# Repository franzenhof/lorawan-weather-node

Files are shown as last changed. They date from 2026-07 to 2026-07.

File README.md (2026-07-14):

# LoRaWAN Weather Node

Firmware for a custom-designed PCB based on a **Heltec WiFi LoRa 32 V3** (ESP32-S3).  
The node measures wind speed, wind direction, rainfall, temperature, humidity, and barometric pressure and transmits the data via **LoRaWAN (OTAA, region configurable; default: EU868)** to a private ChirpStack server.

The images below give a quick impression of the hardware journey from empty PCB to finished node and show how the measured data can be visualized in Grafana.

## Project in Pictures

<table>
  <tr>
    <td align="center" width="33%">
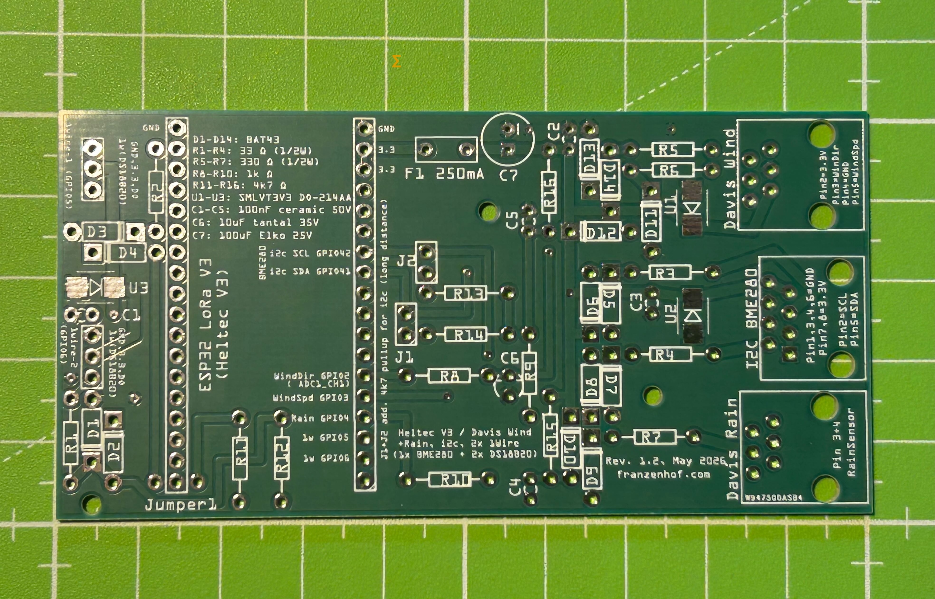
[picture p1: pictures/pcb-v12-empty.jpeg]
PCB Rev 1.2, empty board
      
      <br><strong>PCB, empty</strong>
    </td>
    <td align="center" width="33%">
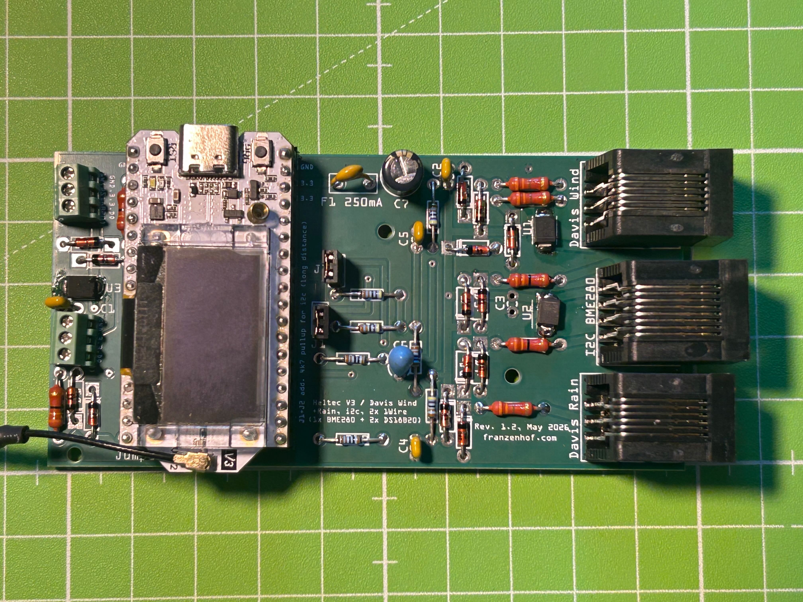
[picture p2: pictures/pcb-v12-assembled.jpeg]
PCB Rev 1.2, assembled board
      
      <br><strong>PCB, assembled</strong>
    </td>
    <td align="center" width="33%">
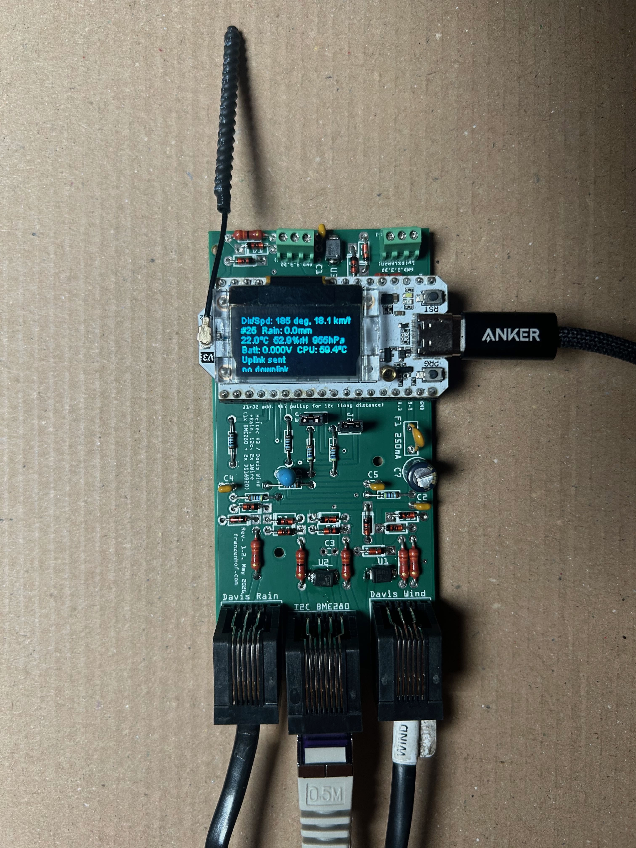
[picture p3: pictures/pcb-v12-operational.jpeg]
PCB Rev 1.2, operational board
      
      <br><strong>PCB, in operation</strong>
    </td>
  </tr>
</table>

<table>
  <tr>
    <td align="center" width="50%">
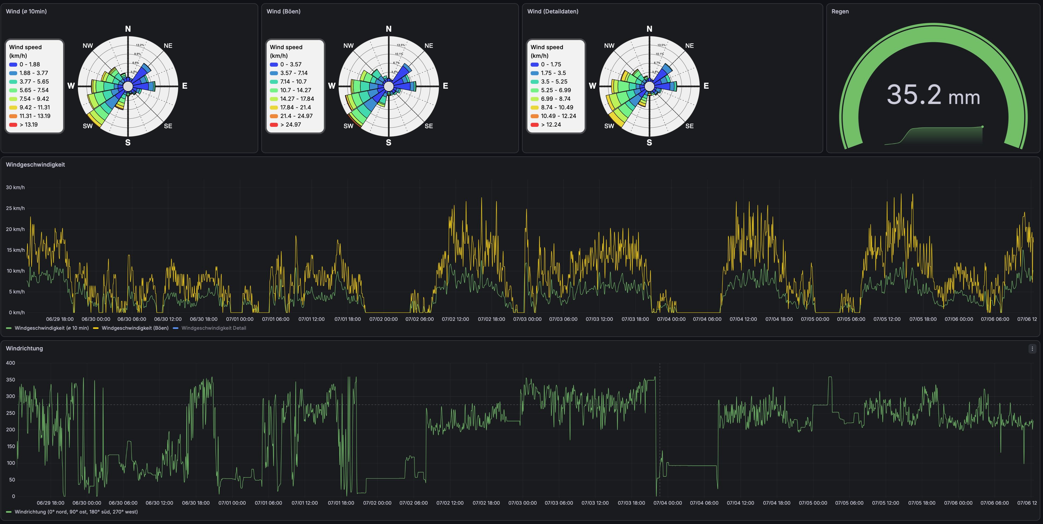
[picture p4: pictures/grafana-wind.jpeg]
Grafana dashboard for wind data
      
      <br><strong>Grafana: wind data</strong>
    </td>
    <td align="center" width="50%">
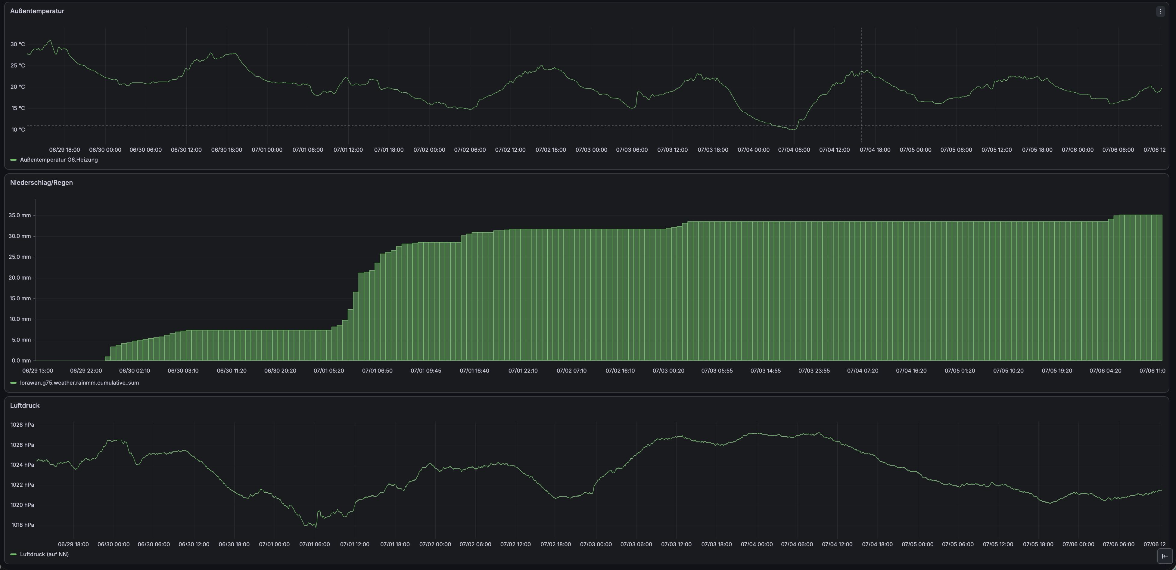
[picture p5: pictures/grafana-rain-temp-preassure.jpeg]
Grafana dashboard for rain, temperature and pressure
      
      <br><strong>Grafana: rain, temperature and pressure</strong>
    </td>
  </tr>
</table>

The following screenshots show the Wi-Fi configuration flow. This setup is designed to be quick and beginner-friendly, even without USB tools.

<table>
  <tr>
    <td align="center" width="50%">
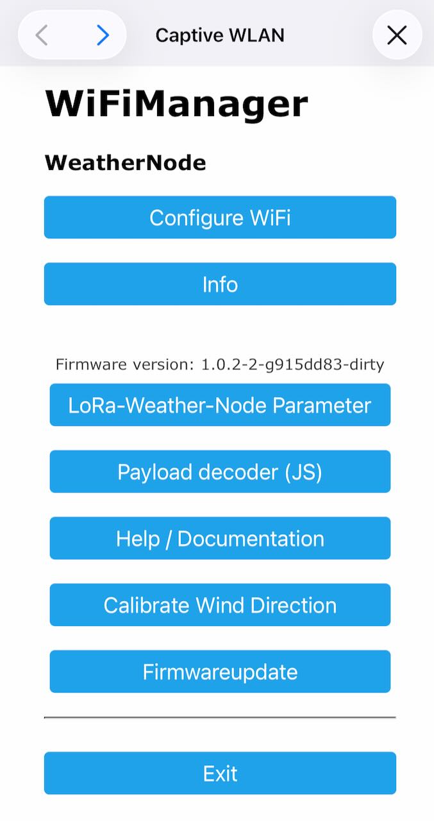
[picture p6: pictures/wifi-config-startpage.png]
Wi-Fi manager start page
      
      <br><strong>Wi-Fi manager: start page</strong>
    </td>
    <td align="center" width="50%">
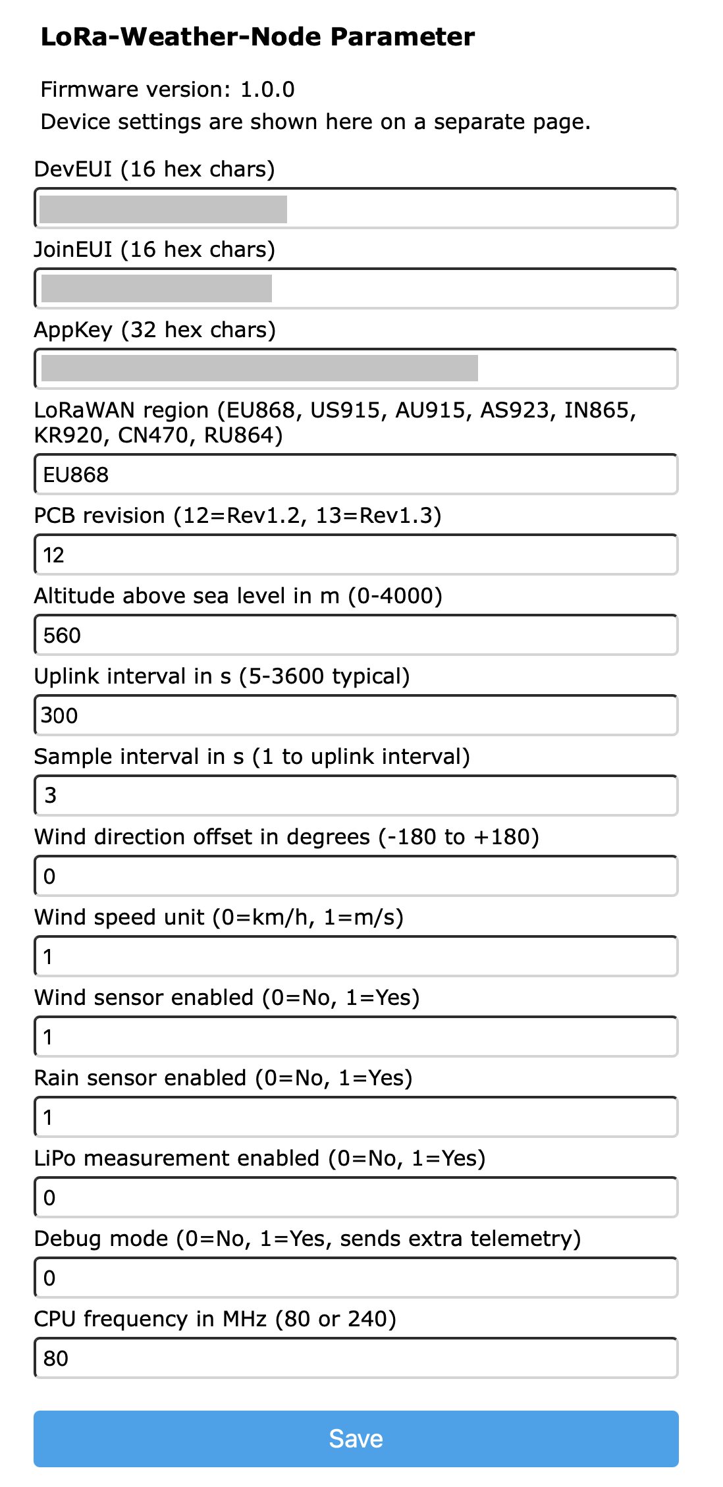
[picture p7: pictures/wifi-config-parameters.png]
Wi-Fi manager parameters page
      
      <br><strong>Wi-Fi manager: parameter page</strong>
    </td>
  </tr>
</table>

<table>
  <tr>
    <td align="center" width="50%">
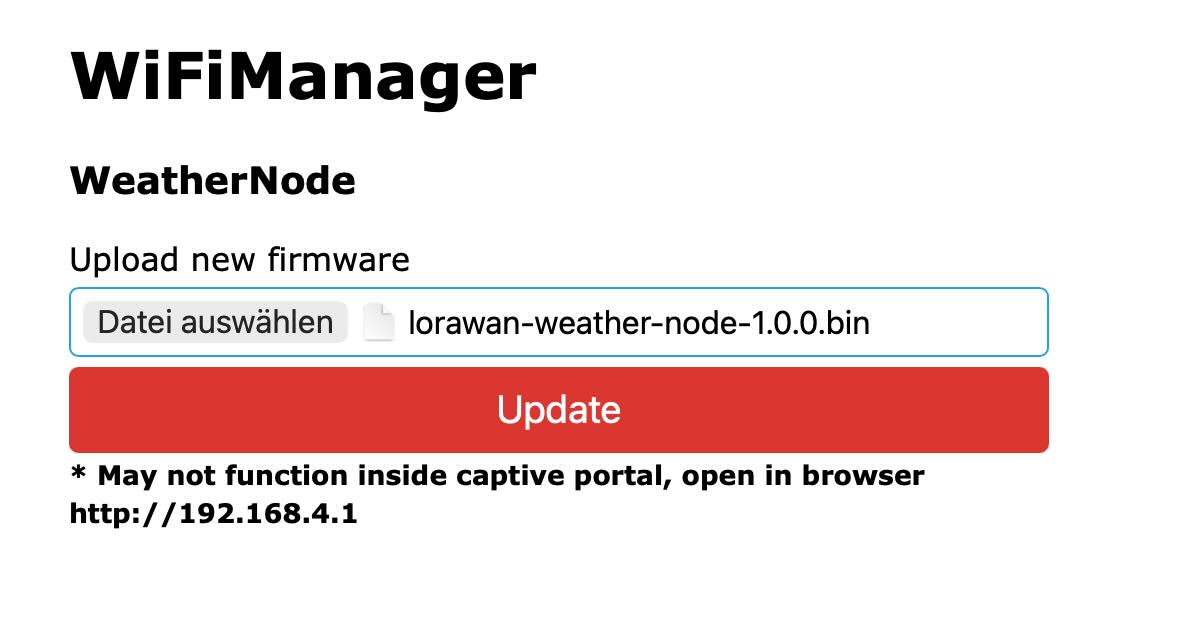
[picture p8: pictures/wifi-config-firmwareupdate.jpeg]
Wi-Fi manager firmware update page
      
      <br><strong>Wi-Fi manager: firmware update</strong>
    </td>
    <td align="center" width="50%">
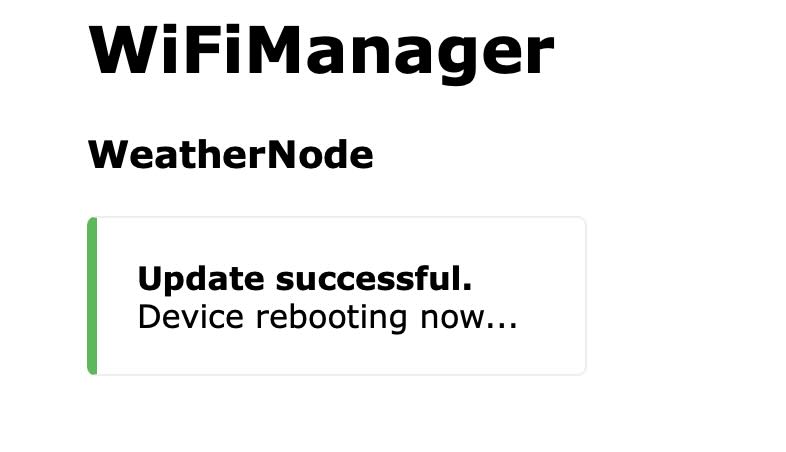
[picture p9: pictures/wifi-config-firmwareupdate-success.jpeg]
Wi-Fi manager firmware update successful
      
      <br><strong>Wi-Fi manager: update successful</strong>
    </td>
  </tr>
</table>

---

## 📄 License & Open Source

This project is fully open-source. To support both software developers and hardware makers, it is dual-licensed:

* **Software / Firmware:** Licensed under the **[MIT License](LICENSE-SOFTWARE)**. You can freely use, modify, and distribute the code.
* **Hardware (Schematics, PCB & 3D Files):** Licensed under the **[CERN-OHL-P v2](LICENSE-HARDWARE)** (CERN Open Hardware Licence – Permissive). You are free to manufacture, modify, and distribute the hardware designs.

*Developed with 🚜 and 💻 by Gerhard Massenbichler at Franzenhof.*

## Use Case

```
[USB-C power supply] ──► [Heltec WiFi LoRa V3]
                              │        │
                   [Davis 6410]    [BME280 via RJ45]
                   Wind sensor           │
                   │                [DS18B20 × 3]
                   [Davis AeroCone]  [LiPo optional]
                   Rain sensor
                              │
                              [LoRaWAN (default EU868)]
                              │
                       [ChirpStack server]
```

The node runs continuously (no deep sleep), measures without interruption, and transmits a LoRaWAN uplink every configurable number of seconds. Typical uplink interval: 60–300 seconds.

---

## Hardware

| Component | Function |
|---|---|
| Heltec WiFi LoRa 32 V3 | Microcontroller (ESP32-S3), LoRa SX1262, OLED display 128×64 |
| Davis 6410 Anemometer | Wind speed (reed switch) + wind direction (potentiometer 20 kΩ) |
| Davis AeroCone / Standard (typically 6466M) | Rainfall (reed switch, 0.2 mm/pulse) |
| BME280 | Temperature / humidity / barometric pressure (I²C 0x76, up to 2 m RJ45 cable) |
| DS18B20 | Up to 3 temperature sensors (1-Wire, external) |
| LiPo battery | Optional; voltage measurement via voltage divider + ADC |
| Custom PCB Rev 1.2 / 1.3 | ESD protection, pull-ups, RC filter, polyfuse |

### Custom PCB

In addition to mechanically connecting the connectors, the PCB provides the following protection functions for all external interfaces:

- **TVS diodes** (SMLVT3V3) directly at each external connector as primary ESD coarse protection  
- **BAT43 Schottky clamp diodes** as secondary protection clamps before the GPIO pins  
- **Series resistors** (330 Ω / 1 kΩ) for current limiting  
- **RC low-pass filter** (4.7 kΩ + 100 nF, τ ≈ 0.47 ms) for hardware debouncing of the reed switches  
- **Polyfuse F1** (250 mA) for short-circuit protection of the 3.3 V sensor supply  
- **Additional I²C pull-ups** (4.7 kΩ, jumper J1/J2) for longer BME280 cable runs up to 2 m

---

## GPIO Pinout

### Fixed Pins (revision-independent)

| GPIO | Function | Direction | Note |
|---|---|---|---|
| **0** | User button | IN (pull-up) | Short press: display 20 s; long press (≥ 3 s): Wi-Fi portal |
| **1** | LiPo ADC | IN (ADC1_CH0) | Voltage divider R13/R14 (390 Ω / 100 Ω) |
| **37** | BAT_CTRL | OUT | HIGH enables ADC measurement path (Heltec V3 internal from board rev. 3.2) |
| **41** | I²C SDA (BME280) | IN/OUT | Wire2, 50 kHz, address 0x76 |
| **42** | I²C SCL (BME280) | OUT | Wire2 |

### Revision-Dependent Pins

| GPIO Rev 1.2 | GPIO Rev 1.3 | Function |
|:---:|:---:|---|
| **2** | **4** | Wind direction ADC (ADC1_CH1) – Davis potentiometer 0–3.3 V → 0–359°, C6 = 10 µF low-pass |
| **3** | **2** | Wind speed (PCNT Unit 0, reed switch) |
| **4** | **5** | Rain (PCNT Unit 1, reed switch) |
| **5** | **6** | 1-Wire bus (DS18B20, up to 3 sensors) |
| **6** | **3** | unused / free |
| – | **47** | 1-Wire high-side switch (OUT, HIGH = bus powered) |

> The active PCB revision is configured in the Wi-Fi portal (default: **13** for Rev 1.3).

### Wind Sensor (Davis 6410) – RJ11 6-pin

| Pin | Color | Function |
|-----|---|---|
| 1 | – | n/c |
| 2 | Yellow | VCC 3.3 V (potentiometer supply) |
| 3 | Green | Wind direction (potentiometer wiper → ADC) |
| 4 | Red | GND |
| 5 | Black | Wind speed (reed switch → PCNT) |
| 6 | – | n/c |

### Rain Sensor (Davis 6466M) – RJ11 6-pin

| Pin | Color | Function |
|-----|---|---|
| 3 | Green/Yellow | Reed switch → PCNT |
| 4 | Red | GND |
| others | – | n/c |

> Wire colors 3 and 4 may be swapped depending on the cable batch – both variants work since the reed switch is polarity-independent.

### BME280 – RJ45 (solder module-side onto breakout board)

| Pins | Function |
|---|---|
| 1, 2, 4, 6 | GND |
| 7, 8 | VCC 3.3 V |
| 3 | SCL |
| 5 | SDA |

> Jumpers J1 and J2 on the PCB activate the additional 4.7 kΩ I²C pull-ups for cable lengths over 0.5 m.

---

## Measurement Principles

### Wind Speed
The Davis 6410 anemometer contains a **reed switch** that closes once per revolution.  
The ESP32 hardware pulse counter (**PCNT**) counts edges without CPU load.  
Conversion per Davis specification:

```
1 revolution/s = 2.25 mph = 3.62 km/h
Wind speed [km/h] = pulses/s × 2.25 × 1.60934
```

The **maximum wind gust** (maximum per uplink interval) is also captured and transmitted separately.

### Wind Direction
The Davis 6410 contains a **potentiometer (20 kΩ)** powered directly from VCC3.3.  
The wiper delivers a linear voltage from 0–3.3 V proportional to 0–359°.  
A configurable **north offset** (–180° to +180°) corrects the mounting orientation.

```
Raw value (0–4095, 12-bit ADC) → map(0, 4095, 0, 359) → + offset → mod 360
```

The low-pass filter C6 (10 µF + potentiometer source impedance ~10 kΩ) gives τ ≈ 100 ms (settling time ~500 ms), which is appropriate for typical vane movement speeds.

### Rainfall
The reed switch in the tipping bucket rain gauge fires one pulse per **0.2 mm of rainfall**.  
PCNT counts pulses in hardware. Rain rate is calculated as mm/h from the interval:

```
Rain [mm] = pulses × 0.2
Rain rate [mm/h] = rain [mm] / (interval [ms] / 3,600,000)
```

The since-start accumulator (`rainMMSinceStart`) survives normal operation in **RTC_DATA_ATTR** (lost on power interruption, resettable via downlink `0x01`).

### Temperatures (DS18B20)
Up to **3 sensors per bus** are detected automatically (`getDeviceCount()`).  
The index corresponds to the order of ROM addresses on the bus.

### Barometric Pressure (BME280)
The measured absolute pressure is converted to **sea level (QNH)** when a station altitude is configured:

```
QNH = absolute pressure × (1 - 0.0000226 × altitude[m])^(-5.255)
```

---

## CayenneLPP Payload Channels

| Channel | Type | Content | Unit | Active when |
|---|---|---|---|---|
| Ch 1 | Direction | Wind direction | ° | `windEn = 1` |
| Ch 1 | Analog Input | Avg wind speed | m/s or km/h | `windEn = 1` |
| Ch 2 | Analog Input | Wind gust (maximum) | m/s or km/h | `windEn = 1` |
| Ch 3 | Analog Input | Rain rate | mm/h | `rainEn = 1` |
| Ch 1 | Distance | Rain current cycle | mm | `rainEn = 1` |
| Ch 2 | Distance | Rain since start | mm | `rainEn = 1` |
| Ch 2 | Digital Input | Status bitfield (BME280, 1-Wire, send-fail count, wind unit) | bitfield | always |
| Ch 200 | Digital Input | Cycle counter (debug) | 0–255 | `debugMode = 1` |
| Ch 202 | Digital Input | Send fail counter (debug) | 0–255 | `debugMode = 1` |
| Ch 201 | Temperature | CPU temperature (debug) | °C | `debugMode = 1` |
| Ch 203 | Analog Input | Free heap (debug) | KiB | `debugMode = 1` |
| Ch 204 | Analog Input | Uptime (debug) | h | `debugMode = 1` |
| Ch 1 | Voltage | LiPo voltage | V | `lipoEn = 1` |
| Ch 1 | Rel. Humidity | Humidity | % | BME280 detected |
| Ch 1 | Baro. Pressure | Barometric pressure QNH | hPa | BME280 detected |
| Ch 2 | Baro. Pressure | Barometric pressure absolute | hPa | BME280 detected |
| Ch 1 | Temperature | BME280 temperature | °C | BME280 detected |
| Ch 2–4 | Temperature | DS18B20 sensor 0–2 | °C | sensor detected |

> **Rain encoding note:** The payload uses the CayenneLPP **Distance** type for rain values, but in this project it is interpreted as **mm** (`rain_cycle_mm`, `rain_since_start_mm`).
> Use the provided decoder in [chirpstack/decoder.js](chirpstack/decoder.js). Generic CayenneLPP decoders might assume meters, but you have to know the values are millimeters.

> In normal operation (`debugMode = 0`) no debug telemetry is sent.

> **Payload size:**  
> Minimal config (DS18B20 only): approx. 15–30 bytes – fits in DR0 (SF12, 51 bytes).  
> Full config (wind + rain + BME280 + 3× DS18B20 + LiPo): approx. 70–75 bytes – requires **DR2 (SF10)** or higher.  
> With a private ChirpStack server and normal gateway distance this is not an issue.

---

## Initial Configuration (Wi-Fi Portal)

### First boot
On first power-up (no DevEUI stored in NVS) the Wi-Fi portal opens **automatically**:

1. The OLED display shows **"Config Portal"**, the AP SSID, the URL and brief instructions
2. Connect your phone or laptop to the Wi-Fi network **"WeatherNode"** (no password)
3. Open **`http://192.168.4.1`** in a browser (most devices redirect automatically)
4. Enter all parameters and click *Save* → the device restarts automatically

### Re-opening the portal later
The portal can be opened at any time in two ways:

| Method | How |
|---|-----|
| **Button long press** | Hold the user button (GPIO 0) for **≥ 3 seconds** during normal operation |
| **LoRaWAN downlink** | Send byte `0x03` on FPort 1 (takes effect after the current send cycle) |

> **Note:** GPIO 0 must **not** be pressed during power-on or reset – this would activate the ESP32 bootloader instead of the firmware. The portal is therefore triggered by a long press *during operation* only.

### Firmware update via Wi-Fi portal (OTA)
Firmware updates can be done wirelessly while the portal is open:

1. Open the Wi-Fi portal (either long press on user button for at least 3 seconds, or LoRaWAN downlink `0x03`)
2. Connect to the board Wi-Fi **WeatherNode**
3. Open **http://192.168.4.1** in a normal browser
4. On the portal start page, click **Firmwareupdate**
5. Upload the `.bin` file and wait until the board reboots

> If the captive portal page does not allow file upload, open **http://192.168.4.1/update** directly in the browser.

| Parameter | Description | Default |
|---|---|---|
| DevEUI | 16 hex chars, from ChirpStack | – |
| JoinEUI | 16 hex chars, from ChirpStack | – |
| AppKey | 32 hex chars, from ChirpStack | – |
| LoRaWAN region | `EU868`, `US915`, `AU915`, `AS923`, `IN865`, `KR920`, `CN470`, `RU864` | EU868 |
| PCB revision | 12 = Rev 1.2, 13 = Rev 1.3 | 13 |
| Altitude above sea level (m) | Station altitude for QNH calculation | 560 |
| Uplink interval (s) | Target interval per measurement cycle | 300 |
| Sample interval (s) | Sub-sample interval within a cycle; ≤ uplink interval | 3 |
| Wind speed unit (0=km/h, 1=m/s) | Unit used for transmitted wind speed and gust values | 1 |
| Wind direction offset (°) | North correction during installation (−180 to +180) | 0 |
| Wind sensor (1=Yes) | Davis wind sensor enabled | 1 |
| Rain sensor (1=Yes) | Davis rain sensor enabled | 1 |
| LiPo measurement (1=Yes) | Voltage measurement via voltage divider enabled | 0 |
| Debug mode (1=Yes) | Adds cycle counter, CPU temp and extra diagnostics in high LPP channels | 0 |
| CPU frequency (80/240 MHz) | 80 MHz saves power; below 80 MHz not allowed (PCNT-APB dependency) | 80 |

> All settings are stored persistently in the **NVS (Non-Volatile Storage)** of the ESP32-S3 and survive restarts and firmware updates.

> Region input in the portal is validated. Unsupported values fall back to **EU868**.

### Debug mode

`debugMode` was introduced to support bench testing (for example without connected weather sensors) and fast diagnostics without affecting normal airtime.

When enabled, the node adds extra telemetry to high LPP channels (200+):

1. Cycle counter
2. CPU temperature
3. Send-fail counter
4. Free heap (KiB)
5. Uptime (hours)

When disabled (default), these values are not part of the uplink payload.

---

## User Button (GPIO 0)

| Press duration | When | Action |
|---|---|---|
| — | First boot (no DevEUI stored) | Wi-Fi portal opens automatically |
| Short press (< 3 s, on release) | Normal operation | Turn on OLED display for 20 s |
| Long press (≥ 3 s) | Normal operation or setup loops (join retries etc.) | Open Wi-Fi config portal → save → restart |

Button presses are detected via a **hardware interrupt** (GPIO CHANGE), so a short press is never missed – even while the LoRa send/receive window is blocking the main task for several seconds.

The display is **off** during normal operation to protect the SSD1306 driver and save power. It turns off automatically after 20 seconds. During the startup sequence (radio init, LoRaWAN join retries) the display stays on permanently so that status and error messages remain visible.

---

## ChirpStack Payload Decoder

The file `chirpstack/decoder.js` contains the JavaScript decoder for ChirpStack v3 and v4.

> **Tip:** The decoder file can also be downloaded directly from the device via the Wi-Fi config portal (*Payload decoder (JS)* button on the start page). The downloaded file is always version-matched to the running firmware.

**Adding the decoder to ChirpStack:**
1. In the ChirpStack web interface: *Device Profiles → Codec → JavaScript codec functions*
2. Paste the contents of `chirpstack/decoder.js`
3. Save – all values will appear as named JSON fields in the uplink events

**Example output (JSON):**
```json
{
  "wind_direction_deg": 247,
  "wind_speed_avg": 12.30,
  "wind_gust": 18.50,
  "rain_rate_mmh": 0.00,
  "rain_cycle_mm": 0.0,
  "rain_since_start_mm": 14.2,
  "cycle_counter": 42,
  "status": {
    "bme280_present": true,
    "bus1_has_sensors": true,
    "send_fail_count": 0,
    "wind_speed_unit": "m/s"
  },
  "battery_v": 3.98,
  "bme280_humidity_pct": 67.5,
  "bme280_pressure_qnh_hpa": 1013.2,
  "bme280_pressure_abs_hpa": 952.1,
  "bme280_temperature_c": 21.3,
  "ds18b20_0_c": 18.6,
  "ds18b20_1_c": 19.1
}
```

**Rain accumulator evaluation:**  
`rain_since_start_mm` is a cumulative counter. The delta between two received packets gives the actual rainfall – even if packets were lost in between.

---

## TTN (The Things Stack) Instead of Private ChirpStack

The node can be used with TTN/TTS as well. No payload format change is required, because the uplink is still standard CayenneLPP and the same decoder logic can be used.

### What to configure

1. In the Wi-Fi portal, set **LoRaWAN region** to the matching regional plan of your TTN deployment (for Europe typically `EU868`).
2. In TTN, create an end device using **OTAA**, LoRaWAN 1.0.x profile, and copy **DevEUI / JoinEUI / AppKey** into the node portal.
3. Add the payload formatter (JavaScript) in TTN by reusing [chirpstack/decoder.js](chirpstack/decoder.js) logic (field names can stay the same).

### Fair-use and practical intervals (EU868)

TTN strongly favors low airtime and low uplink rates. Practical guidance for weather telemetry:

1. Prefer **60 s to 300 s** uplink intervals.
2. Avoid high-spreading-factor operation with very short intervals.
3. Keep payload compact (disable unused sensors in the portal).

For TTN community networks, very short uplink intervals are generally not appropriate and may violate fair-use expectations depending on data rate and gateway conditions.

For TTN operation, keep `debugMode` disabled except for short troubleshooting windows.

### Do you need further firmware changes for TTN?

In most cases: **no functional code changes** are required. The key points are correct region and OTAA credentials.

---

## LoRaWAN Downlink Commands

Downlinks are sent on **FPort 1** with a single byte:

| Byte | Function |
|---|---|
| `0x01` | Reset rain accumulator (rain since start) to 0 |
| `0x02` | Restart device (triggers a new OTAA join) |
| `0x03` | Open Wi-Fi config portal (takes effect after the current send cycle completes) |
| `0x04` | Enable debug mode (persistent) |
| `0x05` | Disable debug mode (persistent) |

Parameter updates are sent on **FPort 1** with command `0x10`:

`[0x10, paramId, valueMSB, valueLSB, ...]`

Multiple parameter triplets may be included in one downlink. Values are interpreted as signed 16-bit and validated.

| Param ID | Parameter | Valid range / values |
|---|---|---|
| `1` | `uplinkIntervalSec` | `5..3600` |
| `2` | `sampleSec` | `1..uplinkIntervalSec` |
| `3` | `windEn` | `0` or `1` |
| `4` | `rainEn` | `0` or `1` |
| `5` | `lipoEn` | `0` or `1` |
| `6` | `debugMode` | `0` or `1` |
| `7` | `windDirOffsetDeg` | `-180..180` |
| `8` | `windUnitMs` | `0` or `1` |
| `9` | `cpuFreqMhz` | `80` or `240` |

Valid parameters are stored persistently in NVS immediately.

---

## Error Handling / Robustness

### Watchdog Timer
A **hardware watchdog** (120 s timeout) protects against hanging code.  
It is activated only **after a successful LoRaWAN join** – allowing slow joins and Wi-Fi portal operation to run without a WDT reset.

### Automatic Restart on Send Failures
After **10 consecutive send failures** an automatic restart is triggered to renew the LoRaWAN join (e.g. after gateway outage or session timeout).

### ADC Averaging
Wind ADC (direction) and battery ADC are averaged over **8 samples** to reduce ESP32-S3 ADC noise.

---

## Uplink Interval and Timing

The configured uplink interval is a **target value**: at the end of each cycle the code only waits the remaining time until the target interval (`millis()` delta). This prevents the measurement time (1-Wire conversion ~750 ms, LoRa airtime ~500 ms) from adding up twice.

```
Cycle start → measure → send → sleep(max(0, target − elapsed))
```

`Sample interval` and `Uplink interval` have different roles:

- **Sample interval** (`sampleSec`): defines how often sub-samples are taken within one uplink cycle.
- **Uplink interval** (`uplinkIntervalSec`): defines when one uplink is generated from the accumulated sub-samples.

Within one send cycle, values are combined as follows:

- **Wind speed (avg)**: arithmetic mean of all wind speed sub-samples.
- **Wind gust (max)**: maximum wind speed seen in all sub-samples of that cycle.
- **Wind direction**: vector average (sin/cos) across all sub-samples.
- **Rain cycle**: sum of rain pulses within the cycle.
- **Rain rate**: derived from the cycle rain amount and full cycle duration.
- **BME280 temperature/humidity/pressure**: arithmetic mean of all BME280 sub-samples.
- **DS18B20 temperatures**: measured once per uplink cycle (not sub-sampled/averaged over `sampleSec`).

**Minimum practical interval** in EU868 at DR5 (SF7): ~5 s (duty cycle restriction).  
For TTN/community networks, use significantly longer intervals (typically at least 60 s).  
**Default values:** uplink interval `300 s`, sample interval `3 s`.

---

## PCB Revisions

| Revision | Status | GPIO Wind Speed | GPIO Wind Dir | GPIO Rain | GPIO 1-Wire |
|---|---|:---:|:---:|:---:|:---:|
| **Rev 1.2** | In use | GPIO 3 | GPIO 2 | GPIO 4 | GPIO 5 |
| **Rev 1.3** | In preparation | GPIO 2 | GPIO 4 | GPIO 5 | GPIO 6 |

> Rev 1.3: The 5V input on the PCB (overvoltage protected) connects directly to the **5V pin of the Heltec WiFi LoRa V3** (Pin 2 on the J2 header of the controller board). GPIO 7 is completely free and unused.

> **Note on current firmware:** Both revisions now support only **one** 1-Wire bus (Rev 1.2: GPIO 5, Rev 1.3: GPIO 6). The former second bus is no longer addressed by the software.

**Changes in Rev 1.3 vs. 1.2:**
- TVS diode (SMLVT3V3 / U4) added at rain sensor connector
- GPIO numbers shifted by one (GPIO 3 was close to JTAG)
- 2nd 1-Wire bus removed; GPIO 6 freed → slot used for the 5V input

---

## Project Structure

```
├── src/
│   └── main.cpp             # Complete firmware
├── chirpstack/
│   └── decoder.js           # ChirpStack v3/v4 JavaScript payload decoder
├── pcblayout/
│   ├── pcb-layout with esd protection.fzz        # Fritzing Rev 1.3
│   ├── pcb-layout with esd protection_Schaltplan.png
│   ├── pcb-layout with esd protection_Leiterplatte.png
│   ├── pcb-layout with esd protection_bom.html
│   ├── pcb-layout with esd protection rev12.zip  # Gerber files Rev 1.2
│   ├── pcb-layout with esd protection rev13.zip  # Gerber files Rev 1.3
│   └── design_readme.txt    # Connector pin assignments
├── platformio.ini
└── README.md
```

---

## Libraries

| Library | Version | Purpose |
|---|---|---|
| RadioLib | ^7.6.0 | LoRaWAN stack (OTAA, EU868) |
| Heltec_ESP32_LoRa_v3 | ^0.9.2 | Board support (display, heltec_temperature) |
| LoRaWAN_ESP32 | ^1.2.0 | LoRaWAN session management (persistence) |
| CayenneLPP | ^1.6.1 | Payload encoding |
| WiFiManager | ^2.0.16-rc.2 | Wi-Fi configuration portal |
| Adafruit BME280 | ^2.2.4 | BME280 driver |
| Adafruit Unified Sensor | ^1.1.15 | Sensor abstraction |
| OneWire | ^2.3.8 | 1-Wire protocol |
| DallasTemperature | ^4.0.6 | DS18B20 driver |
| esp_task_wdt | (IDF built-in) | Hardware watchdog |

---

## Technical Notes

### PCNT and CPU Frequency
The hardware pulse counter (PCNT) uses the **APB clock** for its debounce filter.  
At CPU frequencies ≥ 80 MHz (PLL mode) the APB clock stays constant at 80 MHz.  
Below 80 MHz (XTAL mode) the APB clock drops proportionally → debounce filter timing becomes invalid.  
**Minimum allowed CPU frequency: 80 MHz.**

### 1-Wire with Runtime-Configured Pins
Because the GPIO numbers for 1-Wire are determined at runtime from the PCB revision, the `OneWire` and `DallasTemperature` objects are allocated on the heap with `new` (no static constructor with hard-coded pins possible).

### LoRaWAN Session Persistence
The `LoRaWAN_ESP32` library stores the LoRaWAN session (frame counters, DevAddr, session keys) in NVS. A restart does not necessarily trigger a new OTAA join.

### ADC Linearity
The ESP32-S3 ADC is non-linear (especially below 150 mV and above 3.1 V). For the wind direction potentiometer this is uncritical since values are mapped to 0–359° and the absolute measurement error remains < 5° in practice. For the battery voltage measurement a calibration factor is included in the code.

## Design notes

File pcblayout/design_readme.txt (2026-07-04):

All ESP32-Inputs connecting to Davis sensors are ESD protected (should protect against nearby lightning). 

i2c bus for bme280 sensor:
– Additional 4k7 pullups can be activated by jumper J1 and J2 for longer (max. 2 meter) distances. ESP32 pullups alone might be too weak. 

1wire bus:
- 4k7 Pullups
- Arduino default-Pinout: GND,VCC,DO

Original Rj11 jacks from the Davis-Sensors will fit to the terminals. 
Windsensor: 
- Pin 1: n/c
- Pin 2: 3.3 Volt (yellow wire)
- Pin 3: winddirection (potentiometer, green wire)
- Pin 4: ground/gnd (red wire)
- Pin 5: Windspeed (reedswitch, black wire)
- Pin 6: n/c

Rainsensor (wirecolor 3 and 4 might be swapped, this is no problem): 
- Pin 1: n/c
- Pin 2: n/c
- Pin 3: Windspeed (reedswitch, green/yellow wire)
- Pin 4: ground/gnd (red wire)
- Pin 5: n/c
- Pin 6: n/c

BME280 Sensor (use a rj45 jack and solder the bme280 onto it). CAT6-Cable with up to 2 (perhaps 3) meter length should work. Activate pullups on the board (J1 and J2)
- Pin 1,2,4,6 = Ground/gnd
- Pin 7,8 = VCC 3.3 Volt 
- Pin 2 = SCL
- Pin 5 = SDA

Jumper 1 is a simple flying lead. This was necessary because there was no longer any space available on the PCB for this connection.

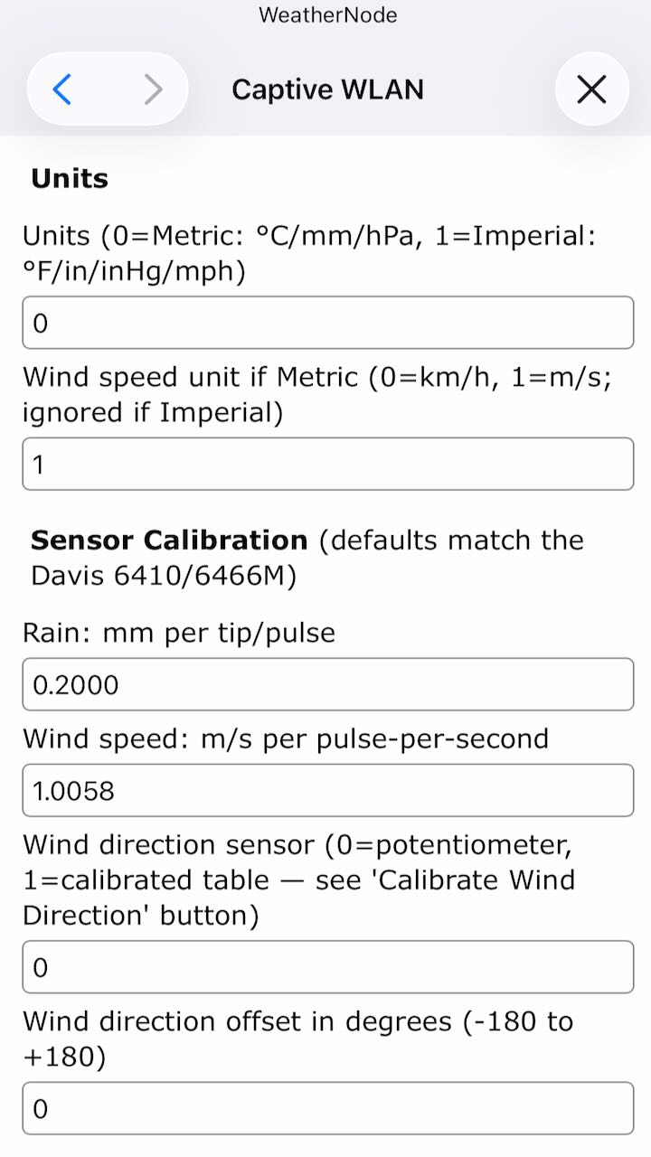
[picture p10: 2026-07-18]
pictures/wifi-config-unitsandsensor.png

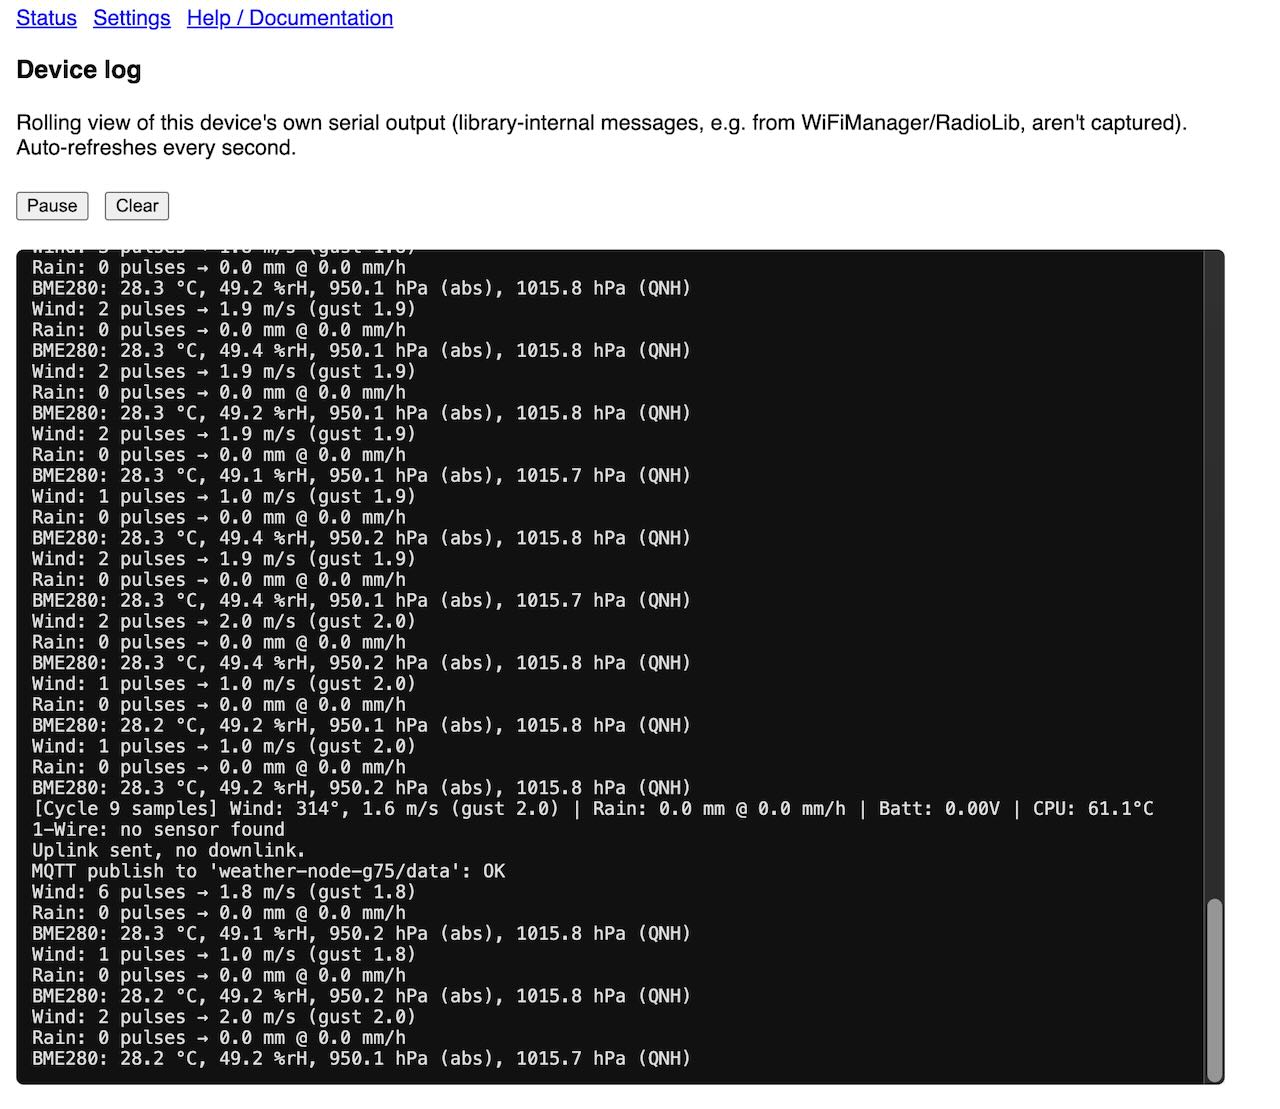
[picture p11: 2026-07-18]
pictures/wifi-logconsole.png

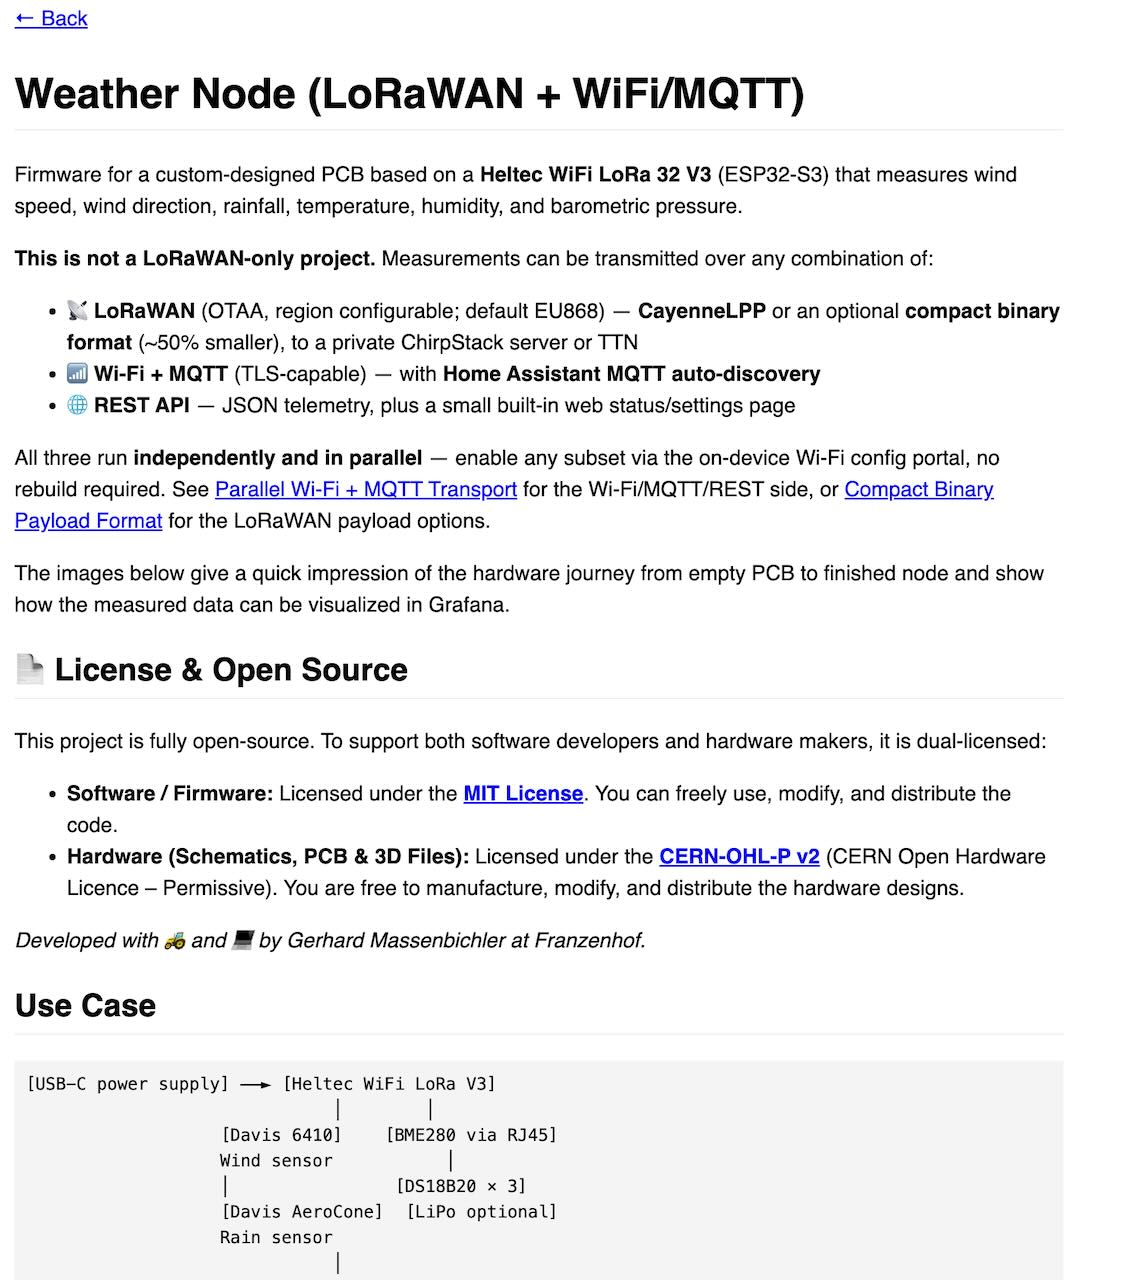
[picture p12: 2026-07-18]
pictures/wifi-helppage.png

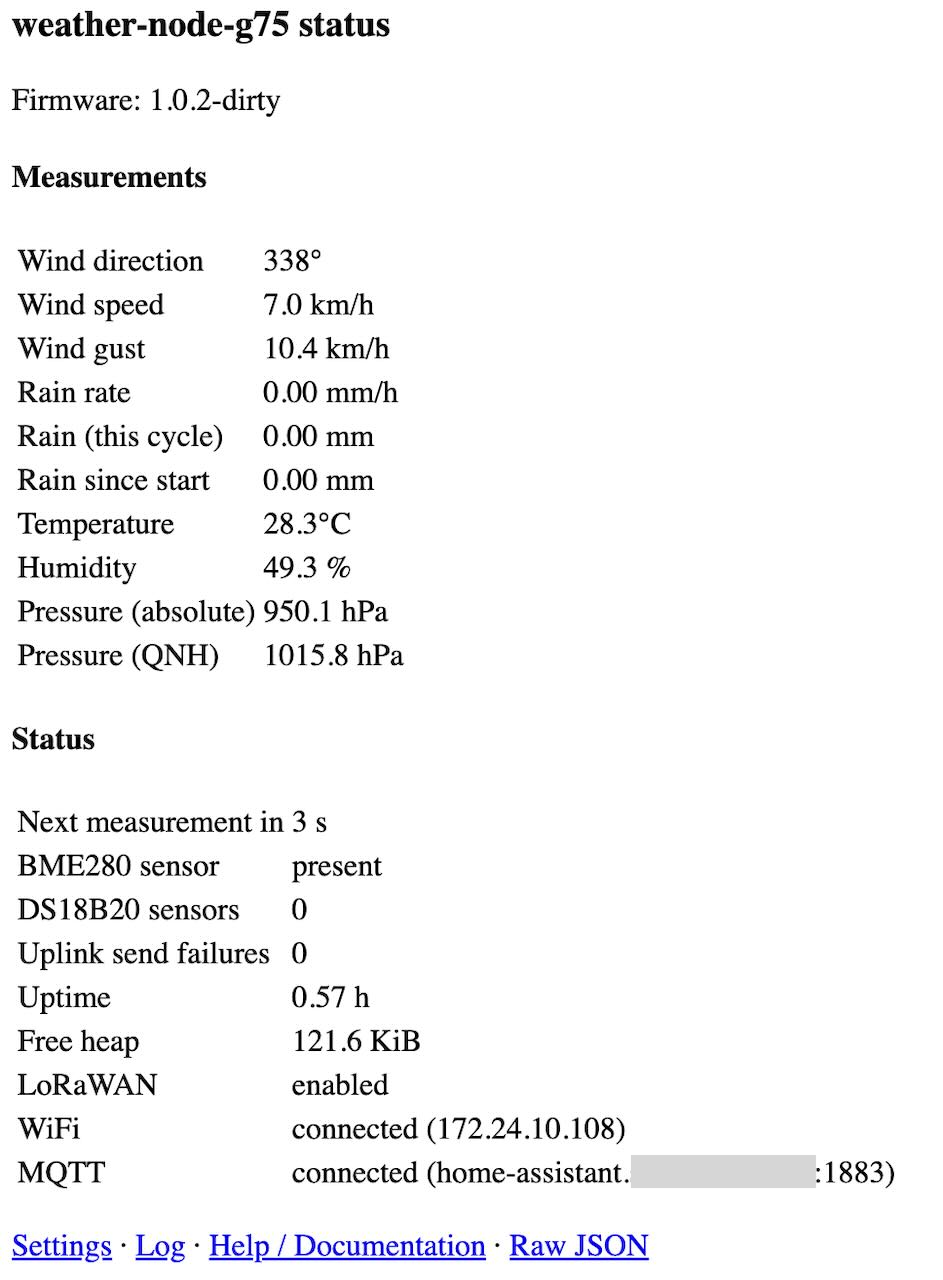
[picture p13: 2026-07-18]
pictures/wifi-statuspage.png

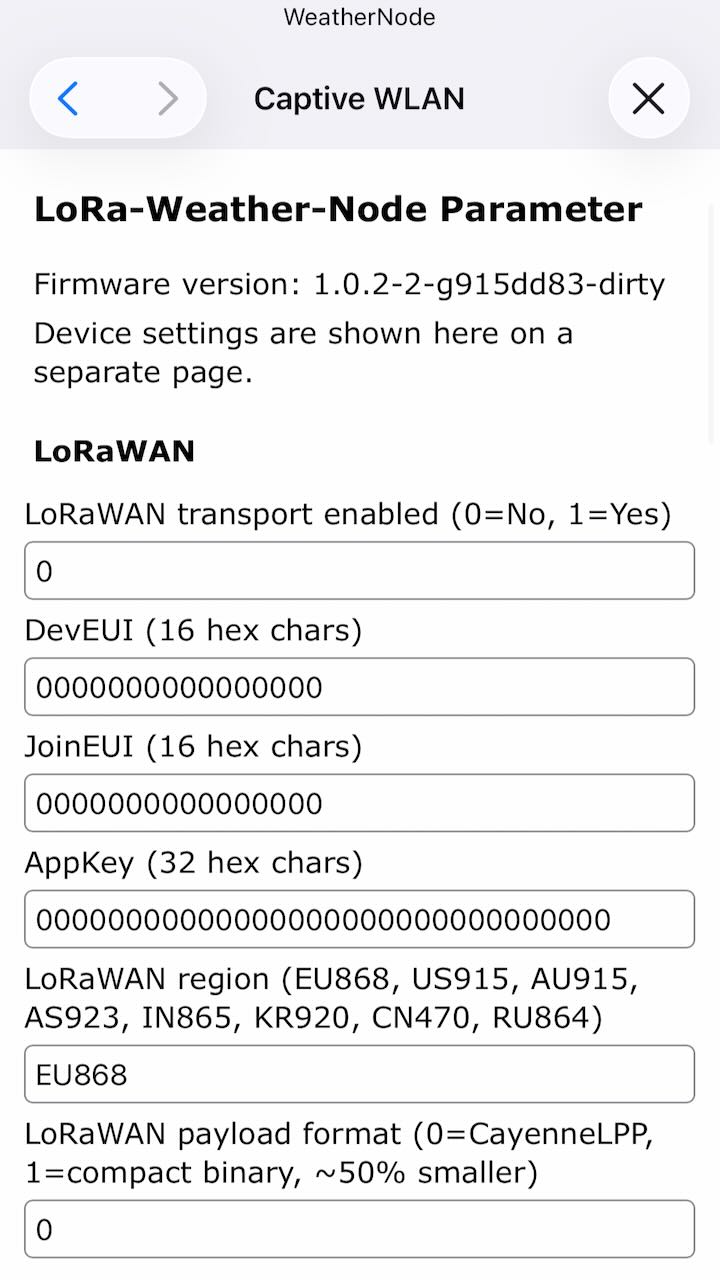
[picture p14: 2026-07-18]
pictures/wifi-config-loraparameter.png

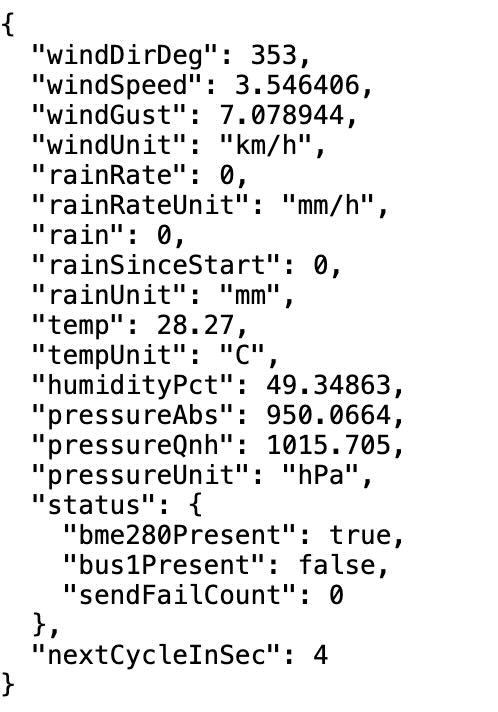
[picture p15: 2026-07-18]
pictures/wifi-rest-json.png

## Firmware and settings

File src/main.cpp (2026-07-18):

#include <Arduino.h>

/**
 * LoRaWAN Weather Node – Heltec WiFi LoRa V3
 *
 * Sensors:
 *   - Davis rain sensor     (reed switch, PCNT)
 *   - Davis wind sensor     (reed switch wind speed PCNT + potentiometer direction ADC)
 *   - BME280                (temperature, humidity, barometric pressure – I2C)
 *   - DS18B20 Bus 1         (up to 3 sensors, 1-Wire)
 *   - LiPo battery          (voltage measurement via voltage divider + ADC, optional)
 *
 * Transmission: CayenneLPP via LoRaWAN EU868 → own ChirpStack server
 *
 * Configuration: Hold user button (GPIO 0) during boot to open the Wi-Fi
 * portal (SSID: WeatherNode). On first boot (no DevEUI stored) the portal
 * opens automatically. All parameters are stored in NVS.
 *
 * Button operation:
 *   Press → turn on display for 20 s
 *
 * LoRaWAN downlink commands (FPort 1, 1 byte):
 *   0x01 → reset rain accumulator (since start)
 *   0x02 → restart device
 *   0x03 → open Wi-Fi config portal (takes effect after current send cycle)
 *   0x04 → enable debug mode (persistent)
 *   0x05 → disable debug mode (persistent)
 *   0x10 → set parameter(s): [0x10, paramId, valueMSB, valueLSB, ...]
 *           paramId 1..14 (signed 16-bit values, validated — see params.cpp
 *           for the full list, also reachable via MQTT and the web settings page)
 *   0xFF → factory reset: wipe all config (NVS) and restart into the
 *           first-boot config portal
 *
 * LPP channel mapping:
 *   Ch  1 Direction        → wind direction (°, if wind sensor enabled)
 *   Ch  1 Analog Input     → avg wind speed (m/s or km/h, if wind sensor enabled)
 *   Ch  2 Analog Input     → wind gust max (m/s or km/h, if wind sensor enabled)
 *   Ch  3 Analog Input     → rain rate (mm/h, if rain sensor enabled)
 *   Ch200 Analog Input     → free heap (KiB, debug mode only)
 *   Ch204 Analog Input     → uptime (h, debug mode only)
 *   Ch  1 Distance         → rain current cycle (mm, if rain sensor enabled)
 *   Ch  2 Distance         → rain since start (mm, if rain sensor enabled)
 *   Ch  2 Digital Input    → status byte: Bit0=BME280, Bit1=Bus1, Bit2-5=errors, Bit6=imperial units, Bit7=wind unit
 *   Ch200 Digital Input    → cycle counter (0–255, debug mode only)
 *   Ch202 Digital Input    → send fail counter (0-255, debug mode only)
 *   Ch  1 Voltage          → LiPo voltage (V, optional)
 *   Ch  1 Rel. Humidity    → humidity (%, BME280)
 *   Ch  1 Baro. Pressure   → barometric pressure QNH (hPa, BME280)
 *   Ch  2 Baro. Pressure   → barometric pressure absolute (hPa, BME280)
 *   Ch  1 Temperature      → temperature (°C, BME280)
 *   Ch  2–4 Temperature    → DS18B20 Bus 1 sensor 0–2 (°C)
 *   Ch201 Temperature      → CPU temperature (°C, debug mode only)
 *
 * File layout: this file is orchestration only (setup/loop, sampling,
 * button, LoRaWAN send). See sensors.cpp (sensor reads), lora_payload.cpp
 * (CayenneLPP/binary encoding), portal.cpp (Wi-Fi config portal + web
 * routes), config.cpp (NVS), params.cpp (shared downlink/MQTT parameters),
 * wifi_mqtt.cpp / web_api.cpp (parallel WiFi+MQTT transport).
 */

// ============================================================================
// INCLUDES
// ============================================================================
#include <heltec_unofficial.h>
#include <LoRaWAN_ESP32.h>
#include <pins_arduino.h>
#include <esp_task_wdt.h>
#include <esp_netif.h>
#include <esp_event.h>
#include "config.h"
#include "globals.h"
#include "params.h"
#include "units.h"
#include "wifi_mqtt.h"
#include "web_api.h"
#include "sensors.h"
#include "lora_payload.h"
#include "portal.h"
#include "serial_log.h"
#include "partition_repair.h"

// ============================================================================
// DISPLAY MANAGEMENT
// ============================================================================
static unsigned long displayUntilMs = 0;

static void activateDisplay(unsigned long durationMs = 20000)
{
    displayUntilMs = millis() + durationMs;
    display.displayOn();
}

static void updateDisplayState()
{
    if (displayUntilMs > 0 && millis() >= displayUntilMs) {
        displayUntilMs = 0;
        display.displayOff();
    }
}

// ============================================================================
// BUTTON HANDLER (GPIO 0, active LOW)
//   Short press (< 3 s, on release) → turn display on for 20 s
//   Long press  (≥ 3 s)            → open config portal, then restart
//
// Note: GPIO0 must NOT be held during power-on/reset (triggers bootloader).
//       The portal is therefore only opened via long press during operation,
//       or automatically on first boot (no DevEUI stored).
//
// An ISR on CHANGE captures press and release timestamps so that button
// events are never missed, even while sendLoRa() blocks for several seconds.
// The ISR only writes volatile variables; all actual actions happen in the
// main context via handleButton().
// ============================================================================
Config gCfg;

static volatile unsigned long isrPressedAtMs  = 0;
static volatile unsigned long isrReleasedAtMs = 0;
static volatile bool          isrPressEvent   = false;
static volatile bool          isrReleaseEvent = false;

void IRAM_ATTR buttonISR()
{
    // Simple software debounce: ignore edges < 50 ms after the previous one
    static unsigned long lastEdgeMs = 0;
    unsigned long now = millis();
    if (now - lastEdgeMs < 50) return;
    lastEdgeMs = now;

    if (digitalRead(BUTTON) == LOW) {
        isrPressedAtMs = now;
        isrPressEvent  = true;
    } else {
        isrReleasedAtMs = now;
        isrReleaseEvent = true;
    }
}

// Runs the config portal, persists the result, shows a status screen, and
// restarts. Shared by all three portal-entry paths (button long-press,
// first boot, LoRaWAN-downlink 0x03), which otherwise duplicated this exact
// sequence. `showStartScreen` is skipped on first boot, where setup()'s own
// boot banner already covers it (runConfigPortal() shows its own "Starting
// config portal..." message immediately anyway).
static void openPortalSaveAndRestart(bool showStartScreen = true)
{
    if (showStartScreen) {
        activateDisplay(5000);
        display.clear();
        display.drawString(0,  0, "Config Portal");
        display.drawString(0, 16, "starting...");
        display.display();
        delay(1000);
    }
    // Free port 80 before WiFiManager's own captive-portal web server tries
    // to bind it — our REST API's WebServer can still be sitting on it from
    // normal operation (only wifiEn/webApiEn toggling off stops it
    // otherwise), and two listeners on the same port is at best undefined,
    // at worst leaves the portal's own server unable to bind at all. This is
    // very likely why the portal was reliable right after a fresh boot
    // (webApiSetup()'s server hasn't started yet at that point) but not on a
    // later, manually-triggered invocation during normal operation.
    webApiStop();
    // Unsubscribe from the task watchdog before entering the portal. It's
    // added to this (loop) task at the very end of setup() — so the
    // first-boot automatic portal call (which runs before that point) was
    // never at risk, but any later, manually-triggered invocation (button/
    // downlink/MQTT) runs with the 120 s watchdog already armed. WiFiManager's
    // startConfigPortal() blocks here for as long as the user takes to fill
    // in the form, without ever calling esp_task_wdt_reset() (that only
    // happens once per our own loop() iteration, which isn't running while
    // blocked here) — so a user taking longer than 120 s would get the
    // watchdog resetting the device mid-session, before saveConfig() is ever
    // reached. Since every portal exit leads to ESP.restart() regardless of
    // outcome, there's no need to re-subscribe afterward. Harmless no-op if
    // this is the first-boot call, where the task was never subscribed yet.
    esp_task_wdt_delete(nullptr);
    gCfg = runConfigPortal(gCfg);
    gCfg.provisioned = 1;
    saveConfig(gCfg);
    display.clear();
    display.drawString(0,  0, "Config saved!");
    display.drawString(0, 16, "Restarting...");
    display.display();
    delay(2000);
    ESP.restart();
}

static void handleButton()
{
    static unsigned long pressedAtMs = 0;
    static bool          longFired   = false;

    // Consume ISR press event (falling edge)
    if (isrPressEvent) {
        isrPressEvent = false;
        pressedAtMs   = isrPressedAtMs;
        longFired     = false;
    }

    // Consume ISR release event (rising edge)
    if (isrReleaseEvent) {
        isrReleaseEvent = false;
        if (!longFired && (isrReleasedAtMs - pressedAtMs) < 3000) {
            activateDisplay(20000);
        }
    }

    // Long press: button currently held for ≥ 3 s
    if (!longFired && pressedAtMs > 0 && (digitalRead(BUTTON) == LOW)
            && (millis() - pressedAtMs >= 3000)) {
        longFired = true;
        openPortalSaveAndRestart();
    }
}

// Waits 'ms' milliseconds, polling the button every 50 ms.
// This ensures the button stays responsive during blocking setup loops.
static void waitWithButtonPoll(unsigned long ms)
{
    unsigned long start = millis();
    while (millis() - start < ms) {
        handleButton();
        vTaskDelay(50 / portTICK_PERIOD_MS);
    }
}

// ============================================================================
// HARDWARE OBJECTS
// ============================================================================
LoRaWANNode* loRaNode = nullptr;

// ============================================================================
// MEASUREMENT DATA
// ============================================================================
RTC_DATA_ATTR uint8_t loopCount = 0;

int  sendFailCount            = 0;
bool portalRequestedViaDownlink = false;

// ============================================================================
// SAMPLING ACCUMULATORS
// A sub-sample is taken every sampleSec seconds (max. uplinkIntervalSec).
// At the end of the uplink interval accumulators are reduced to final values.
// Wind direction: vector averaging (sin/cos) so that 350°+10° → 0° is correct.
// ============================================================================
static float         windDirSinSum    = 0.0f;
static float         windDirCosSum    = 0.0f;
static float         windSpeedSum     = 0.0f;
static float         bme280TempSum    = 0.0f;
static float         bme280PressAbsSum = 0.0f;
static float         bme280PressSeaSum = 0.0f;
static float         bme280HumSum     = 0.0f;
static float         rainCycleMm      = 0.0f;
static int           subSampleCount   = 0;
static unsigned long lastSampleMs     = 0;
unsigned long        lastSendMs       = 0;

// Set while a send cycle is waiting on the non-blocking DS18B20 conversion
// (see loop()) — sampling/next-cycle checks are frozen during this window,
// exactly like they were while readOneWire() used to block for it.
static bool          sendPending      = false;
static unsigned long sendElapsedMs    = 0;

// ============================================================================
// SAMPLING FUNCTIONS
// ============================================================================

// Reset accumulators (call after each transmission)
static void resetAccumulators()
{
    windDirSinSum     = 0.0f;
    windDirCosSum     = 0.0f;
    windSpeedSum      = 0.0f;
    bme280TempSum     = 0.0f;
    bme280PressAbsSum = 0.0f;
    bme280PressSeaSum = 0.0f;
    bme280HumSum      = 0.0f;
    rainCycleMm       = 0.0f;
    subSampleCount    = 0;
    loopCount++;   // increment cycle counter after transmission
    // windGustMs is intentionally left untouched here (see takeSample()):
    // resetting it eagerly would make it read 0 — while windSpeedMs still
    // shows the just-finished cycle's average — for however long it takes
    // the new cycle's first sub-sample to arrive. Live consumers (Wi-Fi
    // status page, REST API, MQTT) read these globals at arbitrary moments,
    // not just right after a transmission, so that gap was directly
    // observable as "wind speed has a value, gust is still 0".
}

// Take one sub-sample (called every sampleMs)
static void takeSample()
{
    // Reset the gust baseline for the new cycle right before its first real
    // reading overwrites it (see resetAccumulators() above for why this
    // can't just happen there), so windGustMs never sits at a stale 0 while
    // windSpeedMs still reflects the previous cycle.
    if (subSampleCount == 0) windGustMs = 0.0f;

    readPulseCounters();   // windSpeedMs, windGustMs, rainMM, rainMMSinceStart

    if (gCfg.windEn) {
        uint16_t dir = readWindDirection();
        float rad     = dir * DEG_TO_RAD;
        windDirSinSum += sinf(rad);
        windDirCosSum += cosf(rad);
        windSpeedSum  += windSpeedMs;
    }
    if (gCfg.rainEn)
        rainCycleMm += rainMM;

    if (bme280Present) {
        readBme280();
        bme280TempSum     += bme280TempC;
        bme280PressAbsSum += bme280PressAbs;
        bme280PressSeaSum += bme280PressSea;
        bme280HumSum      += bme280Humidity;
    }
    subSampleCount++;
}

// Calculate final values from accumulators (once per send cycle)
static void computeFinalValues(unsigned long elapsedMs)
{
    if (subSampleCount == 0) return;

    if (gCfg.windEn) {
        // Vector-average wind direction: circular arithmetic correct (350°+10° → 0°)
        float avgSin  = windDirSinSum / subSampleCount;
        float avgCos  = windDirCosSum / subSampleCount;
        int   angleDeg = (int)roundf(atan2f(avgSin, avgCos) * RAD_TO_DEG);
        windDirection = (uint16_t)((angleDeg % 360 + 360) % 360);
        windSpeedMs   = windSpeedSum / subSampleCount;
        // Gust should not be lower than the cycle average, otherwise some
        // dashboard queries may treat gust as missing at very short sample windows.
        if (windGustMs < windSpeedMs) windGustMs = windSpeedMs;
    }
    if (gCfg.rainEn) {
        rainMM      = rainCycleMm;
        // Guard: avoid astronomically high rate on very short first cycle
        rainRateMmH = (elapsedMs >= 1000)
                      ? rainCycleMm / ((float)elapsedMs / 3600000.0f)
                      : 0.0f;
    }
    if (bme280Present) {
        bme280TempC    = bme280TempSum    / subSampleCount;
        bme280PressAbs = bme280PressAbsSum / subSampleCount;
        bme280PressSea = bme280PressSeaSum / subSampleCount;
        bme280Humidity = bme280HumSum     / subSampleCount;
    }

    cpuTemperature = heltec_temperature();
    batteryVolt    = gCfg.lipoEn ? readBatteryVoltage() : 0.0f;

    dbgSerial.printf("[Cycle %d samples] Wind: %d°, %.1f m/s (gust %.1f) | "
                  "Rain: %.1f mm @ %.1f mm/h | Batt: %.2fV | CPU: %.1f°C\n",
                  subSampleCount, windDirection, windSpeedMs, windGustMs,
                  rainMM, rainRateMmH, batteryVolt, cpuTemperature);
}

// Thin LoRaWAN-specific parser: byte-frame commands map onto the shared,
// transport-agnostic actions in params.cpp/h, which are also reachable via
// the MQTT command topic (see wifi_mqtt.cpp).
static void processDownlink(const uint8_t* data, size_t len)
{
    if (len < 1) return;

    switch (data[0]) {
        case 0x01:
            cmdResetRainAccumulator();
            break;
        case 0x02:
            cmdRestart();
            break;
        case 0x03:
            cmdRequestConfigPortal();
            break;
        case 0x04:
            cmdSetDebugMode(true);
            break;
        case 0x05:
            cmdSetDebugMode(false);
            break;
        case 0xFF:
            cmdFactoryReset();
            break;
        case 0x10: {
            // Format: [0x10, paramId, valueMSB, valueLSB, ...] (1..9)
            if (len < 4 || ((len - 1) % 3) != 0) {
                dbgSerial.println("Downlink: invalid parameter payload length.");
                break;
            }
            bool anyApplied = false;
            for (size_t i = 1; i + 2 < len; i += 3) {
                uint8_t paramId = data[i];
                int16_t value = (int16_t)(((uint16_t)data[i + 1] << 8) | data[i + 2]);
                bool ok = applyDownlinkParam(paramId, value);
                dbgSerial.printf("Downlink: set param %u = %d -> %s\n",
                              paramId, value, ok ? "OK" : "INVALID");
                anyApplied = anyApplied || ok;
            }
            if (anyApplied) {
                saveConfig(gCfg);
            }
            break;
        }
        default:
            dbgSerial.printf("Downlink: unknown command 0x%02X\n", data[0]);
            break;
    }
}

static void sendLoRa()
{
    uint8_t downlinkData[256] = {};
    size_t  lenDown = sizeof(downlinkData) - 1;

    // payloadFormat selects the uplink encoding + FPort; downlink handling
    // (processDownlink()) is unaffected either way.
    const uint8_t* txBuf;
    size_t         txLen;
    uint8_t        txPort;
    if (gCfg.payloadFormat == 1) {
        txBuf = binBuf; txLen = binLen; txPort = 3;
    } else {
        txBuf = (const uint8_t*)lpp.getBuffer(); txLen = lpp.getSize(); txPort = 1;
    }

    int16_t state = loRaNode->sendReceive(txBuf, txLen, txPort, downlinkData, &lenDown);

    char buf[64];
    if (state == RADIOLIB_ERR_NONE) {
        dbgSerial.println("Uplink sent, no downlink.");
        sendFailCount = 0;
        display.drawString(0, 44, "Uplink sent");
        display.drawString(0, 55, "no downlink");
    } else if (state > 0) {
        dbgSerial.printf("Uplink + Downlink (%d bytes), SNR: %.1f dB, RSSI: %.1f dBm\n",
                      lenDown, radio.getSNR(), radio.getRSSI());
        sendFailCount = 0;
        processDownlink(downlinkData, lenDown);
        display.drawString(0, 44, "Uplink + Downlink");
        snprintf(buf, sizeof(buf), "SNR %.1f  RSSI %.1f", radio.getSNR(), radio.getRSSI());
        display.drawString(0, 55, buf);
    } else {
        dbgSerial.printf("Send failed (code %d), attempt %d/10\n", state, ++sendFailCount);
        display.drawString(0, 44, "Send error");
        snprintf(buf, sizeof(buf), "Code %d  Attempt %d/10", state, sendFailCount);
        display.drawString(0, 55, buf);
        if (sendFailCount >= 10) {
            dbgSerial.println("Too many send failures – restarting for new join.");
            delay(1000);
            ESP.restart();
        }
    }
}
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
void loop()
{
    esp_task_wdt_reset();
    handleButton();
    updateDisplayState();
    wifiMqttPoll();   // non-blocking; no-op unless wifiEn is set
    webApiPoll();     // non-blocking; no-op unless wifiEn+webApiEn are set

    const unsigned long now           = millis();
    const unsigned long sendTargetMs  = (unsigned long)gCfg.uplinkIntervalSec * 1000UL;
    // Sample interval from config; never larger than uplink interval
    const unsigned long sampleMs      = min((unsigned long)gCfg.sampleSec * 1000UL, sendTargetMs);

    // ── Take sub-sample ────────────────────────────────────────────────────
    if (!sendPending && now - lastSampleMs >= sampleMs) {
        lastSampleMs = now;
        takeSample();
    }

    // ── Uplink when target interval reached ───────────────────────────────
    if (!sendPending && now - lastSendMs >= sendTargetMs) {
        sendElapsedMs = now - lastSendMs;
        lastSendMs    = now;

        computeFinalValues(sendElapsedMs);
        startOneWireConversion();   // non-blocking; finished off below once ready
        sendPending = true;
    }

    // ── Finish the pending send once the DS18B20 conversion is ready ──────
    // pollOneWireConversion() returns false immediately if the ~750 ms
    // conversion isn't done yet, so loop() (button, WiFi/MQTT poll, watchdog)
    // keeps running normally in the meantime instead of stalling on it —
    // matters most at short cycle times (WiFi/MQTT-only nodes can go down to
    // a few seconds, where a blocking 750 ms wait would be a large fraction
    // of the whole cycle).
    if (sendPending && pollOneWireConversion()) {
        sendPending = false;

        if (gCfg.loraEn) {
            if (gCfg.payloadFormat == 1) buildBinaryPacket();
            else                          buildLppPacket();
        }

        // Display update and LoRa send are independent conditions - keep
        // them as separate statements rather than duplicating the loraEn
        // check across both display-state branches.
        if (displayUntilMs > 0) drawDisplay();
        if (gCfg.loraEn)        sendLoRa();
        if (displayUntilMs > 0) display.display();

        mqttPublishTelemetry();   // no-op unless wifiEn+mqttEn and currently connected

        resetAccumulators();

        if (portalRequestedViaDownlink) {
            portalRequestedViaDownlink = false;
            openPortalSaveAndRestart();
        }
    }

    vTaskDelay(50 / portTICK_PERIOD_MS);   // short yield, no busy-wait
}

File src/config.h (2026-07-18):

#pragma once

#include <Arduino.h>
#include <stdint.h>

// MQTT transport security. Standard broker ports: 1883 = plain (no TLS),
// 8883 = TLS — but the broker's actual configuration is what matters, not
// the port number itself.
enum MqttTlsMode {
    MQTT_TLS_NONE     = 0,  // plain TCP, no TLS at all — required for brokers
                            // listening without TLS (classic port 1883)
    MQTT_TLS_INSECURE = 1,  // TLS, but the server certificate is not verified
                            // (e.g. self-signed, no CA configured) — encrypted,
                            // not authenticated
    MQTT_TLS_VERIFY   = 2,  // TLS, server certificate verified against mqttCaCert
};

// ============================================================================
// CONFIGURATION (persistent via NVS / Preferences)
// ============================================================================
struct Config {
    // Set once the config portal has been completed the first time. Used
    // instead of devEui==0 to detect "needs first-time setup", since a
    // WiFi/MQTT-only node (loraEn=0) may never set a non-zero DevEUI.
    int      provisioned        = 0;

    uint64_t joinEui           = 0;
    uint64_t devEui            = 0;
    uint8_t  appKey[16]        = {};
    char     region[8]         = "EU868"; // LoRaWAN region (default)
    int      pcbVersion        = 13;  // 12 = Rev 1.2, 13 = Rev 1.3
    int      altitudeM         = 560; // default altitude above sea level (m)
    int      uplinkIntervalSec = 300;  // target uplink interval (s)
    int      sampleSec         = 3;    // sub-sample interval (s); <= uplinkIntervalSec
    int      windDirOffsetDeg  = 0;   // north offset (added to raw value, mod 360)
    int      windUnitMs         = 1;   // 1 = transmit wind in m/s, 0 = transmit in km/h
    int      windEn            = 1;   // 1 = Davis wind sensor enabled (direction + speed)
    int      rainEn            = 1;   // 1 = Davis rain sensor enabled
    int      lipoEn            = 0;   // 1 = LiPo measurement enabled (saves 4 LPP bytes when 0)
    int      debugMode         = 0;   // 1 = include debug telemetry in payload
    int      cpuFreqMhz        = 80;  // 80 or 240 MHz; below 80 not allowed (PCNT-APB)
    int      payloadFormat     = 0;   // 0 = CayenneLPP (FPort 1), 1 = compact binary (FPort 3, ~50% smaller)
    int      unitSystem        = 0;   // 0 = Metric (°C, mm, hPa, wind per windUnitMs), 1 = Imperial (°F, in, inHg, mph)

    // ------------------------------------------------------------------
    // Generic (non-Davis) sensor calibration
    // ------------------------------------------------------------------
    float    rainMmPerTip      = 0.2f;      // mm of rain per reed-switch pulse (Davis default: 0.2mm)
    float    windMsPerPps      = 1.00584f;  // wind speed (m/s) per pulse-per-second (Davis default)
    int      windDirSensorType = 0;         // 0 = continuous potentiometer (linear map), 1 = calibrated lookup table (e.g. reed-switch/resistor-ladder vanes)
    int      windDirCalCount   = 0;         // number of valid entries in the calibration table below (0 = not calibrated)
    uint16_t windDirCalAdc[16] = {};        // raw ADC reading captured per calibration position
    uint16_t windDirCalDeg[16] = {};        // corresponding direction in degrees per calibration position
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

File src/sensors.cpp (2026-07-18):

#include "sensors.h"
#include "globals.h"
#include "serial_log.h"

#include "driver/pcnt.h"
#include <Wire.h>
#include <Adafruit_Sensor.h>
#include <Adafruit_BME280.h>
#include <OneWire.h>
#include <DallasTemperature.h>

// ============================================================================
// SENSOR STATE (declared extern in globals.h)
// ============================================================================
bool     bme280Present  = false;
float    bme280TempC    = 0.0f;
float    bme280PressAbs = 0.0f;
float    bme280PressSea = 0.0f;
float    bme280Humidity = 0.0f;

float    bus1Temps[MAX_SENSORS_PER_BUS];
int      bus1Count = 0;

float    windSpeedMs   = 0.0f;
float    windGustMs    = 0.0f;
float    rainMM        = 0.0f;
float    rainRateMmH   = 0.0f;
uint16_t windDirection = 0;
float    batteryVolt   = 0.0f;
float    cpuTemperature = 0.0f;

RTC_DATA_ATTR float rainMMSinceStart = 0.0f;

namespace {

TwoWire            Wire2(1);
Adafruit_BME280    bme;
OneWire*           oneWireBus1 = nullptr;
DallasTemperature* sensorsBus1 = nullptr;

PinSet gPins = { 3, 4, 5 };   // set by sensorsInit()

bool windPcntConfigured = false;
bool rainPcntConfigured = false;
int16_t pulsesLastCountWindspeed = 0;
int16_t pulsesLastCountRain      = 0;
unsigned long previousMillis     = 0;

} // namespace

PinSet getPins(int pcbVersion)
{
    if (pcbVersion == 13) return { 4, 5, 6 };
    return { 3, 4, 5 };
}

void configureWindPcnt()
{
    if (!windPcntConfigured) {
        pcnt_config_t pcnt_wind = {
            .pulse_gpio_num = gPins.windSpeed,
            .ctrl_gpio_num  = PCNT_PIN_NOT_USED,
            .pos_mode       = PCNT_COUNT_INC,
            .neg_mode       = PCNT_COUNT_DIS,
            .counter_h_lim  = 32767,
            .counter_l_lim  = -32768,
            .unit           = PCNT_UNIT_WINDSPEED,
            .channel        = PCNT_CHANNEL_WINDSPEED,
        };
        pcnt_unit_config(&pcnt_wind);
        pcnt_set_filter_value(PCNT_UNIT_WINDSPEED, FILTER_VALUE_WINDSPEED);
        pcnt_filter_enable(PCNT_UNIT_WINDSPEED);
        windPcntConfigured = true;
    }

    pcnt_counter_pause(PCNT_UNIT_WINDSPEED);
    pcnt_counter_clear(PCNT_UNIT_WINDSPEED);
    pcnt_counter_resume(PCNT_UNIT_WINDSPEED);
    pulsesLastCountWindspeed = 0;
}

void configureRainPcnt()
{
    if (!rainPcntConfigured) {
        pcnt_config_t pcnt_rain = {
            .pulse_gpio_num = gPins.rain,
            .ctrl_gpio_num  = PCNT_PIN_NOT_USED,
            .pos_mode       = PCNT_COUNT_INC,
            .neg_mode       = PCNT_COUNT_DIS,
            .counter_h_lim  = 32767,
            .counter_l_lim  = -32768,
            .unit           = PCNT_UNIT_RAIN,
            .channel        = PCNT_CHANNEL_RAIN,
        };
        pcnt_unit_config(&pcnt_rain);
        pcnt_set_filter_value(PCNT_UNIT_RAIN, FILTER_VALUE_RAIN);
        pcnt_filter_enable(PCNT_UNIT_RAIN);
        rainPcntConfigured = true;
    }

    pcnt_counter_pause(PCNT_UNIT_RAIN);
    pcnt_counter_clear(PCNT_UNIT_RAIN);
    pcnt_counter_resume(PCNT_UNIT_RAIN);
    pulsesLastCountRain = 0;
}

void stopWindPcnt()
{
    if (!windPcntConfigured) return;
    pcnt_counter_pause(PCNT_UNIT_WINDSPEED);
    pcnt_counter_clear(PCNT_UNIT_WINDSPEED);
    pulsesLastCountWindspeed = 0;
}

void stopRainPcnt()
{
    if (!rainPcntConfigured) return;
    pcnt_counter_pause(PCNT_UNIT_RAIN);
    pcnt_counter_clear(PCNT_UNIT_RAIN);
    pulsesLastCountRain = 0;
}

void sensorsEarlyInit()
{
    pinMode(PIN_ADC_BATCTRL,       OUTPUT);
    pinMode(PIN_ADC_VOLTBATTERY,   INPUT);
    pinMode(PIN_ADC_WINDDIRECTION, INPUT);
    adcAttachPin(PIN_ADC_VOLTBATTERY);
    adcAttachPin(PIN_ADC_WINDDIRECTION);
    analogReadResolution(12);
}

void sensorsInit(const PinSet& pins)
{
    gPins = pins;

    for (int i = 0; i < MAX_SENSORS_PER_BUS; i++)
        bus1Temps[i] = DEVICE_DISCONNECTED_C;

    // High-side switch for VCC_1WIRE (Rev 1.3+ only)
    if (gCfg.pcbVersion >= 13) {
        pinMode(PIN_1WIRE_HSS, OUTPUT);
        digitalWrite(PIN_1WIRE_HSS, LOW);   // sensors off at startup
        dbgSerial.println("1-Wire HSS (GPIO47) initialized – sensors off.");
    }

    // BME280
    Wire2.begin(PIN_I2C_SDA_BME280, PIN_I2C_SCL_BME280, I2C_FREQUENCY);
    Wire2.setTimeOut(50);
    bme280Present = bme.begin(I2C_ADRESS_BME280, &Wire2);
    if (bme280Present) {
        // Forced mode: sensor only measures on request (takeForcedMeasurement) → ~0 µA idle current
        bme.setSampling(Adafruit_BME280::MODE_FORCED,
                        Adafruit_BME280::SAMPLING_X1,   // Temperatur
                        Adafruit_BME280::SAMPLING_X1,   // Luftdruck
                        Adafruit_BME280::SAMPLING_X1,   // Luftfeuchte
                        Adafruit_BME280::FILTER_OFF,
                        Adafruit_BME280::STANDBY_MS_0_5);
    } else {
        dbgSerial.println("BME280 not found – check wiring.");
    }

    // 1-Wire (pin configured at runtime)
    oneWireBus1 = new OneWire(pins.oneWire);
    sensorsBus1 = new DallasTemperature(oneWireBus1);
    sensorsBus1->begin();

    // PCNT counters are configured once and can be toggled later via downlink.
    if (gCfg.windEn) configureWindPcnt();
    if (gCfg.rainEn) configureRainPcnt();

    previousMillis = millis();
}

int adcAverage(int pin, int samples)
{
    int sum = 0;
    for (int i = 0; i < samples; i++) {
        sum += analogRead(pin);
        delayMicroseconds(200);   // ESP32 ADC: ~200 µs settling time between samples
    }
    return sum / samples;
}

float readBatteryVoltage()
{
    constexpr int   ADC_BITS   = 12;
    constexpr float ADC_MAX    = (1 << ADC_BITS) - 1;
    constexpr float ADC_VREF   = 3.3f;
    constexpr int   R_UPPER    = 390;   // R13
    constexpr int   R_LOWER    = 100;   // R14
    // Calibration measurement: 4.095 V measured when 4.2 V was applied
    constexpr float CAL_FACTOR = (ADC_VREF / ADC_MAX)
                                 * ((R_UPPER + R_LOWER) / (float)R_LOWER)
                                 * (4.2f / 4.095f);

    digitalWrite(PIN_ADC_BATCTRL, HIGH);
    delay(100);
    int raw = adcAverage(PIN_ADC_VOLTBATTERY);
    digitalWrite(PIN_ADC_BATCTRL, LOW);
    return CAL_FACTOR * raw;
}
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

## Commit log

2026-07-04 Release v1.0.0
    [lorawan-weather-node-pcb.fzz]
2026-07-06 feat: Update LPP channel mapping and telemetry for wind and rain sensors
    - Adjusted LPP channel mapping to support both m/s and km/h for wind speed.
    - Added debug channels for free heap and uptime.
    - Updated temperature readings to reflect BME280 sensor data.
    - Enhanced digital input channels for cycle and send fail counters in debug mode.
    - Introduced configuration options for wind speed unit and debug mode.
    - Refactored code to handle new configuration parameters and ensure backward compatibility.
    - Updated display output to show wind speed in the selected unit.
    - Added versioning script to generate firmware version header based on git tags.
    - Included new images for Grafana dashboards and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
    [main.cpp]
2026-07-07 the reverse polarity protection was changed to a crowbar solution
    [lorawan-weather-node-pcb.fzz]
2026-07-14 New feature: ChirpStack JS decoder integrated into the firmware (download via WiFi Manager); bug fix: Rainfall amount is once again transmitted in mm rather than meters via CayenneLPP; additionally, 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
    [decoder_js.h, main.cpp]
2026-07-18 - Added optional Wi-Fi + MQTT transport support alongside LoRaWAN. - Refactored firmware into clearer modules for better maintainability. - Improved captive portal and web UX with dedicated Status, L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
    - Introduced optional Wi-Fi/MQTT transport flow.
    - Added plain MQTT security mode and improved broker/status visibility.
    - Added por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
    [lorawan-weather-node-pcb.fzz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]
